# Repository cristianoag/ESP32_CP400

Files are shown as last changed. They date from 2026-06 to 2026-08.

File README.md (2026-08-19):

# The Retro Hacker Clone Series: ESP32 CP400

<p align="center">
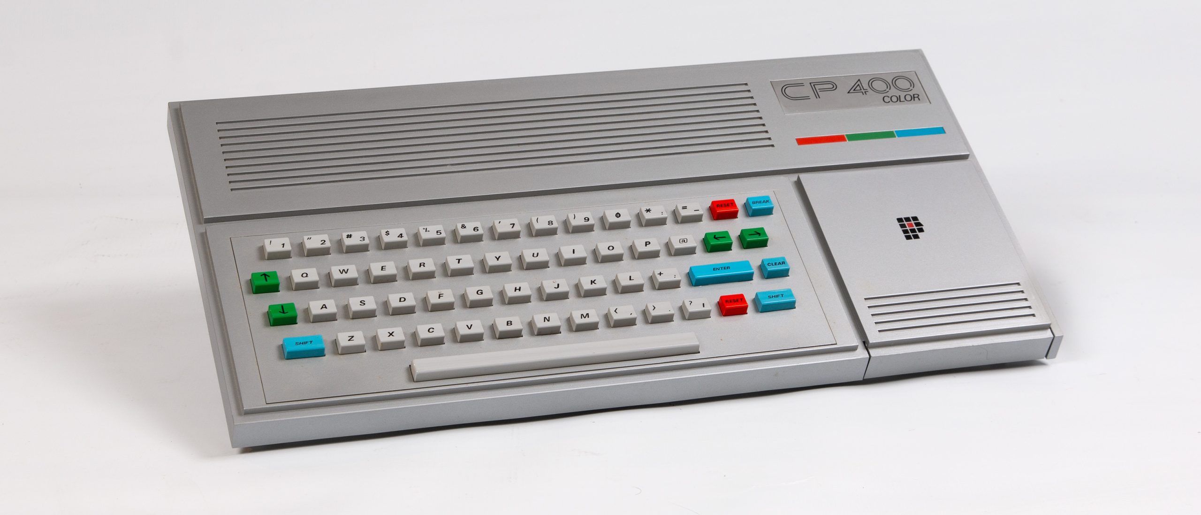
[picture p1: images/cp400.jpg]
Prologica CP 400 computer
	
</p>

An open hardware and software project to recreate the spirit of the Prologica CP 400, the Brazilian TRS-80 Color Computer 2 compatible home computer, using a modern ESP32-S3 based design.

This design is part of the Retro Hacker ESP32 Clone Series: a planned collection of ESP32-based recreations of classic Brazilian computers from the 1980s. Each machine in the series focuses on keeping the original character and software culture alive while using practical, buildable modern hardware.

The goal is not to build a museum prop. The goal is to make a usable, hackable CP400-inspired machine: real connectors, real keyboard and joystick paths, VGA output, SD-backed storage, and firmware that can run a CoCo 2 / CP400 style environment on inexpensive contemporary hardware.

## Why CP400?

The Prologica CP 400 was one of the memorable Brazilian home computers of the mid-1980s. Built during Brazil's market-reserve era, it was compatible with the Tandy/Radio Shack TRS-80 Color Computer 2, known as the CoCo 2, but arrived with its own Brazilian industrial design, PAL-M video expectations, local peripherals, translated software, and a very particular place in the local 8-bit scene.

Under the hood, the original CP400 family followed the CoCo architecture closely:

- Motorola MC6809E CPU running around 0.895 MHz
- Motorola MC6847 video display generator
- 16 KB or 64 KB RAM configurations
- Extended Color BASIC in ROM
- Cassette, cartridge, joystick, serial, video, and expansion interfaces
- Optional disk support through the CP450 floppy system

This repository explores that machine from both sides: hardware that gives the emulator a dedicated physical home, and software that recreates the CP400/CoCo experience on an ESP32-S3.

## Heritage

<p align="center">
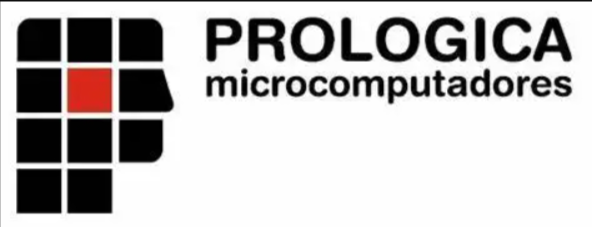
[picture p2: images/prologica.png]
Prologica logo
	
	&nbsp;&nbsp;&nbsp;&nbsp;
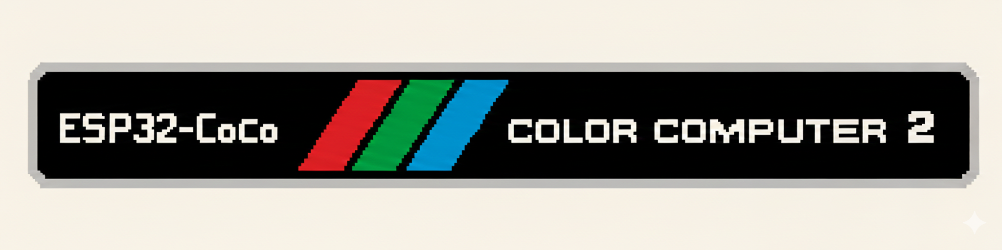
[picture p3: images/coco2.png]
TRS-80 Color Computer 2 logo
	
</p>

The ESP32 CP400 sits between two histories: Prologica's Brazilian CP400 family and the Tandy/Radio Shack CoCo 2 platform that inspired it. The project uses those references as historical anchors while building a new, independent ESP32-based recreation.

## Project Goals

- Preserve the CP400/CoCo 2 experience in a form that can be built, studied, and modified.
- Establish the CP400 entry in the broader ESP32 Clone Series for Retro Hacker.
- Use modern parts where they make sense, especially the ESP32-S3 with PSRAM.
- Provide a KiCad hardware design for a CP400-inspired board and peripheral connectors.
- Run an embedded CoCo 2 style emulator with video, USB input, SD storage, virtual disks, and joystick support.
- Keep the design approachable for retrocomputing builders, hardware hackers, and firmware tinkerers.

## Repository Layout

```text
hardware/esp32_clones/         KiCad project for the generic ESP32 clone hardware
hardware/esp32_clones/libraries Project-local KiCad symbols and footprints
software/esp32_cp400_emulator/ PlatformIO firmware for the ESP32-S3 emulator
case/                          Mechanical/case work area
```

## Hardware

The KiCad project lives in `hardware/esp32_clones` and is named `esp32_clones`.

The local KiCad libraries are organized inside:

```text
hardware/esp32_clones/libraries/symbols
hardware/esp32_clones/libraries/footprints
```

The hardware design currently includes project-local footprints and symbols for the ESP32-S3 module, USB connectors, SD card socket, switches, and other board-level parts. The intent is to give the firmware a board that feels more like a small computer than a loose dev kit on a bench.

## Firmware

The firmware lives in `software/esp32_cp400_emulator` and is built with PlatformIO using the Arduino framework for ESP32-S3.

Current software areas include:

- MC6809 emulator core integration
- CoCo 2 / CP400 video mode handling
- VGA output through the ESP32-S3 VGA library
- USB soft-host input support
- SD/MMC storage access
- Virtual floppy disk image handling
- Emulator menu and firmware updater code
- Joystick and keyboard mapping hooks

The PlatformIO environment is configured for an ESP32-S3 DevKitC-style board with 16 MB flash and 8 MB PSRAM:

```ini
[env:esp32-s3-devkitc-1-Modded]
platform = espressif32@6.11.0
board = esp32-s3-devkitc-1-n16r8
framework = arduino
```

The project intentionally pins the Espressif platform version because newer Arduino/ESP32 combinations may change includes and behavior used by the emulator.

### F12 Firmware Update Package

From `software/esp32_cp400_emulator`, generate a firmware package for the F12 update menu with:

```console
make firmware
```

The command builds the configured PlatformIO environment and creates a versioned package such as `dist/ESP32_CP400-1.11.FLH`. Copy that `.FLH` file to the root of the CP400 microSD card, then select **Firmware update** from the F12 menu.

Set the firmware version with `FW_VERSION` near the top of the Makefile, using one major digit and two minor digits. It is compiled into the F12 menu and used in the package filename. A one-off version can be built without editing the file:

```console
make firmware FW_VERSION=1.11
```

The command names can be overridden when needed, for example:

```console
make firmware PIO=platformio PYTHON=py
```

On Windows, the Makefile automatically detects PlatformIO in `%USERPROFILE%/.platformio/penv/Scripts`. Use `make help` to display the detected command.

Firmware release changes are tracked in `software/esp32_cp400_emulator/docs/log.md`.

## Status

This project is under active development. Expect the hardware, pin mapping, emulator behavior, and documentation to evolve together.

Good entry points:

- Open the KiCad project at `hardware/esp32_clones/esp32_clones.kicad_pro`.
- Open the firmware workspace at `software/esp32_cp400_emulator/esp32_cp400_emulator.code-workspace`.
- Review `software/esp32_cp400_emulator/platformio.ini` before building or uploading.

## ROMs and Original Software

Original CP400, CoCo, Extended Color BASIC, Disk BASIC, cartridge, cassette, and floppy software may still be copyrighted. This repository is for original hardware/firmware work and project files. Bring your own legally obtained ROMs and software images when needed.

## Historical Notes

The CP400 was part of a wider Brazilian TRS-Color ecosystem that included machines such as the Codimex CD-6809, LZ Color 64, Dynacom MX-1600, and Varix VC50. The CP400 became the best-known of the Brazilian CoCo-compatible machines, before the home computer market shifted heavily toward MSX and, later, IBM PC compatibles.

That makes it a particularly interesting target for a modern recreation: it sits at the meeting point of Brazilian microcomputer history, Motorola 6809 elegance, CoCo software culture, and the practical charm of 1980s home computing.

## References and Further Reading

- [Prologica CP-400](https://en.wikipedia.org/wiki/Prol%C3%B3gica_CP-400)
- [CP400](https://pt.wikipedia.org/wiki/CP400)
- [TRS-80 Color Computer](https://en.wikipedia.org/wiki/TRS-80_Color_Computer)
- [Prologica](https://pt.wikipedia.org/wiki/Prol%C3%B3gica)
- [Datassette](https://datassette.org/) for Brazilian retrocomputing manuals, magazines, books, and software preservation material

## License

See `LICENSE.txt` for the repository license. The firmware directory also includes its own `license.txt`; check both before reusing or redistributing project materials.

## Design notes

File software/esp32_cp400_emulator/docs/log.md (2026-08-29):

# Firmware Change Log

This log tracks user-visible changes to the ESP32 CP400 emulator firmware.
Versions use one major digit and two minor digits, for example 1.10 and 1.11.

## 1.13 - Unreleased

### Fixed

- Centered the 256x192 CP400 display area within the active VGA frame in every video mode. Graphics and text modes now share the same origin calculated from the selected VGA resolution instead of using separate manual offsets.

## 1.12 - 2026-08-29

### Changed

- Moved the keyboard port to the ESP32-S3 native USB-OTG host on GPIO19 and GPIO20, so ordinary full speed USB keyboards now work. The previous bit-banged stack could only talk to low speed devices, which is why most keyboards appeared dead or never lit their indicators.
- Requested the HID boot protocol from the keyboard, so keyboards that default to their own report layout still deliver the standard report the emulator expects.
- Turned the native USB serial console off, because the keyboard host and the console cannot share the one USB controller. Serial output and firmware uploads now use the UART port, which already carried the boot log.
- Kept joystick 1 and joystick 2 on the existing bit-banged stack, unchanged.

### Added

- Logged the keyboard's speed, vendor and product IDs, and the interface and endpoint in use, so an unsupported keyboard can be told apart from a power or wiring fault.
- Added `make upload` to build and upload the firmware through the PC USB port configured in `platformio.ini`.
- Added a DELETE action to eject the selected disk image from any of the four drives and persist the empty assignment.

### Fixed

- Removed UART debug writes from the 6809 timer interrupt. They caused an interrupt watchdog reset loop after the USB-OTG keyboard host moved the serial console from native USB CDC to UART0.
- Showed explicit Y/Yes and N/No choices on the firmware installation confirmation screen.
- Waited for ENTER to be released before opening the disk-drive screen, preventing the same key press from immediately opening Drive 0's file picker.

### Notes

- The keyboard connector must be rewired: D- goes to GPIO19 and D+ goes to GPIO20. These pads are tied to the USB PHY inside the chip and cannot be moved to other pins.
- Keyboards containing an internal USB hub are still not supported, because this ESP-IDF version has no hub driver.

## 1.11 - 2026-08-19

### Added

- Added a progress gauge that runs while a firmware update is validated and copied.

### Changed

- Moved the USB keyboard port to GPIO11 and GPIO12, joystick 1 to GPIO15 and GPIO16, and joystick 2 to GPIO17 and GPIO18, to simplify cable routing on the board.
- Gave every F12 screen the same layout, with the product name and screen title in the header, matching separator lines, and key hints in the footer. The disk image picker, firmware update screens, and error messages previously used their own styles.
- Renamed the "Joystick calibration" menu entry to "Joystick setup".
- Turned the joystick Serial debug output off by default.
- Listed only files with a matching extension when choosing a firmware or disk image, hiding folders such as System Volume Information that could not be opened anyway.

## 1.10 - 2026-08-18

### Added

- Added independent joystick 1 and joystick 2 control mapping from the F12 menu.
- Added guided capture for joystick neutral, up, down, left, right, button 1, and button 2 states.
- Added persistent raw HID joystick mappings to support controllers with different report layouts.
- Added a Serial joystick debug mode in the F12 menu that logs raw USB reports, decoded controls, and stored mappings at 115200 baud.
- Added a Makefile workflow that builds, packages, and verifies `.FLH` firmware updates for the F12 menu.
- Added firmware version control through the Makefile and versioned update-package filenames.

### Fixed

- Stored the PIA control registers at $FF01 and $FF03 on write, so the joystick multiplexer select bits change as the machine requests. They were never updated, which froze the multiplexer on a single channel and made every axis read return the same value.
- Restored the CP400 PIA joystick multiplexer order, which had been changed incorrectly and routed joystick 1's horizontal axis to the vertical channel while the horizontal channel read the unused second joystick.
- Centred the default joystick axis values, so a disconnected or silent joystick no longer reads as held fully left and up.
- Prevented an empty comparison mask from matching every direction at once, which cancelled horizontal and vertical movement and left the pointer centred.
- Moved joystick tracing to a dedicated task on the free core, so the video task cannot starve it and Serial output cannot disturb the bit-banged USB timing.
- Routed joystick tracing to the UART0 console used by the rest of the boot output, instead of the separate native USB serial port where it was invisible.
- Mirrored a single connected joystick's axes onto both CP400 joystick channels, so games work regardless of which joystick they read or which USB port the controller uses.
- Logged USB device enumeration with port number and vendor/product IDs, and the stored joystick mappings at boot.
- Replaced whole-report comparison with per-control bit masks so hat switches, buttons, and analog axes are matched independently.
- Excluded report bytes that change while the joystick is at rest, so counters and noisy axes no longer block button detection.
- Mapped either physical joystick button to the CP400's single fire input for that joystick.
- Added automatic detection of the standard Windows PlatformIO CLI installation.
- Corrected `.FLH` package checksums to match the F12 firmware validator.
- Fixed F12 firmware staging so stale or partial update files are replaced and verified before rebooting.

## 1.00 - 2026-08-17

### Added

- First tracked firmware release for the ESP32 CP400 emulator.
- Added CP400/CoCo 2 emulation with VGA output, USB keyboard and joystick input, SD-backed disk images, the F12 system menu, and SD-card firmware updates.

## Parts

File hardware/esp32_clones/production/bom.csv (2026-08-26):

Designator | Footprint | Quantity | Value | LCSC Part #
C1 | CP_Elec_6.3x3 | 1 | 220UF
C2 | 0805 | 1 | C
F1 | 1210 | 1 | Fuse
J1 | PS-12E05 | 1 | ~
J2 | TE_6364372-2 | 1 | Joystick 2
J3 | TE_6364372-2 | 1 | Joystick 1
J4 | TE_6364372-2 | 1 | Keyboard
J5 | Conn_uSDcard | 1 | Micro_SD_Card
J6 | BarrelJack_Horizontal | 1 | Barrel_Jack
J7 | DSUB-15-HD_Socket_Horizontal_P2.29x1.90mm_EdgePinOffset3.03mm_Housed_MountingHolesOffset4.94mm | 1 | DA15_Pins
J8 | PS-22F05 | 1 | ~
J9 | PJ-307 | 1 | AudioJack2_Ground
R1, R4, R6 | 0805 | 3 | 560R
R10 | 0805 | 1 | 1k
R2, R3, R5 | 0805 | 3 | 1.2KR
R7, R8, R9 | 0805 | 3 | 10KR
U1 | ESP32-S3-WROOM-1 | 1 | ~

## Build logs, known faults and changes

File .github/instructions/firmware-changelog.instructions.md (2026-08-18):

---
description: "Maintain the ESP32 CP400 firmware change log whenever firmware behavior, build output, configuration, or user-facing features change."
applyTo: "software/esp32_cp400_emulator/**"
---

# Firmware Change Log

For every incorporated firmware change, update `software/esp32_cp400_emulator/docs/log.md` in the same change set.

- Use the firmware version defined by `FW_VERSION` in `software/esp32_cp400_emulator/Makefile`, formatted as one major digit and two minor digits, for example `1.10`.
- Add concise, user-visible entries under `Added`, `Changed`, `Fixed`, or `Removed` as appropriate.
- Create a new version section when `FW_VERSION` changes; do not rewrite previously released sections.
- Include the release date when it is known. Use `Unreleased` when work targets a version that has not been released yet.
- Do not add entries for formatting-only edits or internal refactors with no firmware, build, configuration, or user-visible effect.

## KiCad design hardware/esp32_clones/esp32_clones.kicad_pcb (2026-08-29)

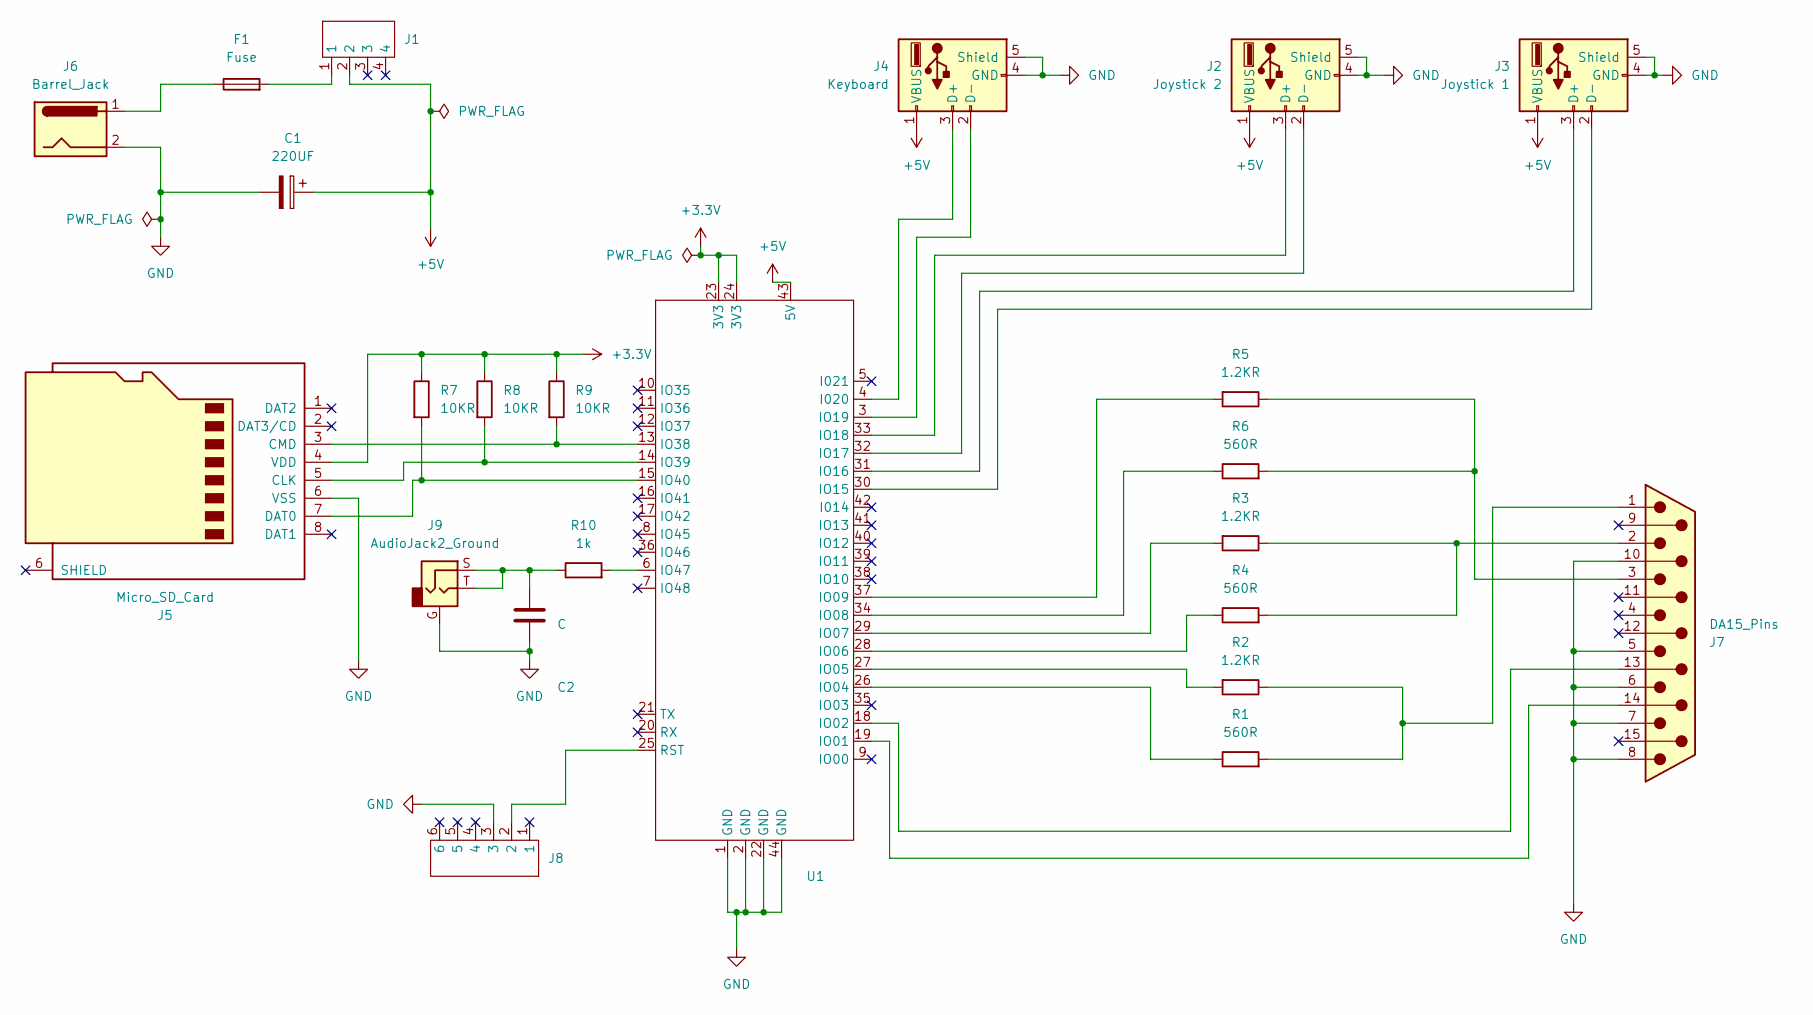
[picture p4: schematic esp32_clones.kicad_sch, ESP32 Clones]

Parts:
C1: 220UF; CP_Elec_6.3x3
C2: C; C_0805_2012Metric_Pad1.18x1.45mm_HandSolder
F1: Fuse; Fuse_1210_3225Metric
J1: PS-12E05
J2: Joystick 2; TE_6364372-2
J3: Joystick 1; TE_6364372-2
J4: Keyboard; TE_6364372-2
J5: Micro_SD_Card; Conn_uSDcard
J6: Barrel_Jack; BarrelJack_Horizontal
J7: DA15_Pins; DSUB-15-HD_Socket_Horizontal_P2.29x1.90mm_EdgePinOffset3.03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
J8: PS-22F05
J9: AudioJack2_Ground; PJ-307
R1, R4, R6: 560R; R_0805_2012Metric_Pad1.20x1.40mm_HandSolder
R2, R3, R5: 1.2KR; R_0805_2012Metric_Pad1.20x1.40mm_HandSolder
R7, R8, R9: 10KR; R_0805_2012Metric_Pad1.20x1.40mm_HandSolder
R10: 1k; R_0805_2012Metric_Pad1.20x1.40mm_HandSolder
U1: ESP32-S3-WROOM-1

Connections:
+3.3V: J5.4 (VDD), R7.1, R8.1, R9.1, U1.23 (3V3), U1.24 (3V3)
+5V: C1.1, J1.2, J2.1 (VBUS), J3.1 (VBUS), J4.1 (VBUS), U1.43 (5V)
GND: C1.2, C2.2, J2.4 (GND), J2.5 (Shield), J3.4 (GND), J3.5 (Shield), J4.4 (GND), J4.5 (Shield), J5.6 (VSS), J6.2, J7.5, J7.6, J7.7, J7.8, J7.10, J8.3, J9.G, U1.1 (GND), U1.2 (GND), U1.22 (GND), U1.44 (GND)
unnamed: C2.1, J9.S, J9.T, R10.1
unnamed: F1.1, J6.1
unnamed: F1.2, J1.1
unnamed: J2.3 (D+), U1.33 (IO18)
unnamed: J2.2 (D-), U1.32 (IO17)
unnamed: J3.3 (D+), U1.31 (IO16)
unnamed: J3.2 (D-), U1.30 (IO15)
unnamed: J4.3 (D+), U1.4 (I020)
unnamed: J4.2 (D-), U1.3 (IO19)
unnamed: J5.5 (CLK), R8.2, U1.14 (IO39)
unnamed: J5.3 (CMD), R9.2, U1.13 (IO38)
unnamed: J5.7 (DAT0), R7.2, U1.15 (IO40)
unnamed: J7.13, U1.18 (IO02)
unnamed: J7.14, U1.19 (IO01)
unnamed: J7.1, R1.2, R2.1
unnamed: J7.2, R3.1, R4.2
unnamed: J7.3, R5.1, R6.2
unnamed: R1.1, U1.26 (IO04)
unnamed: R2.2, U1.27 (IO05)
unnamed: R4.1, U1.28 (IO06)
unnamed: R3.2, U1.29 (IO07)
unnamed: R6.1, U1.34 (IO08)
unnamed: R5.2, U1.37 (IO09)
unnamed: R10.2, U1.6 (IO47)
unnamed: J8.2, U1.25 (RST)

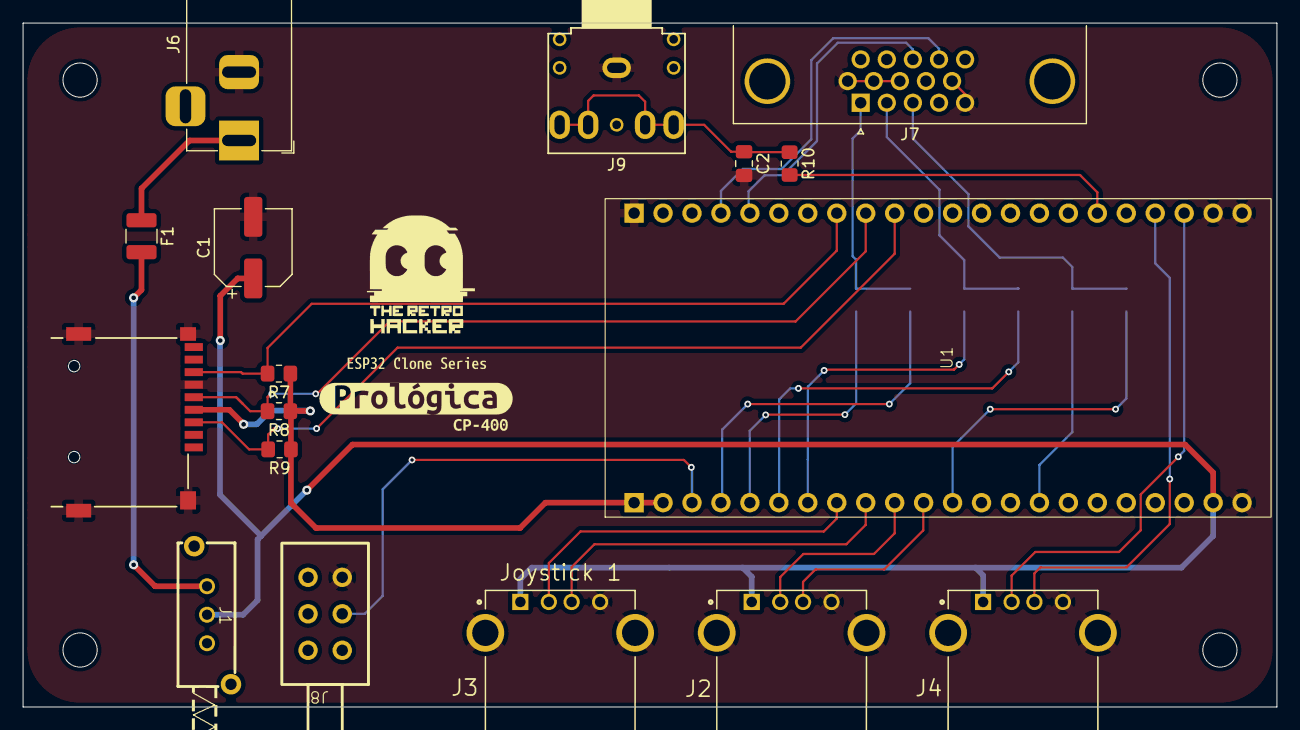
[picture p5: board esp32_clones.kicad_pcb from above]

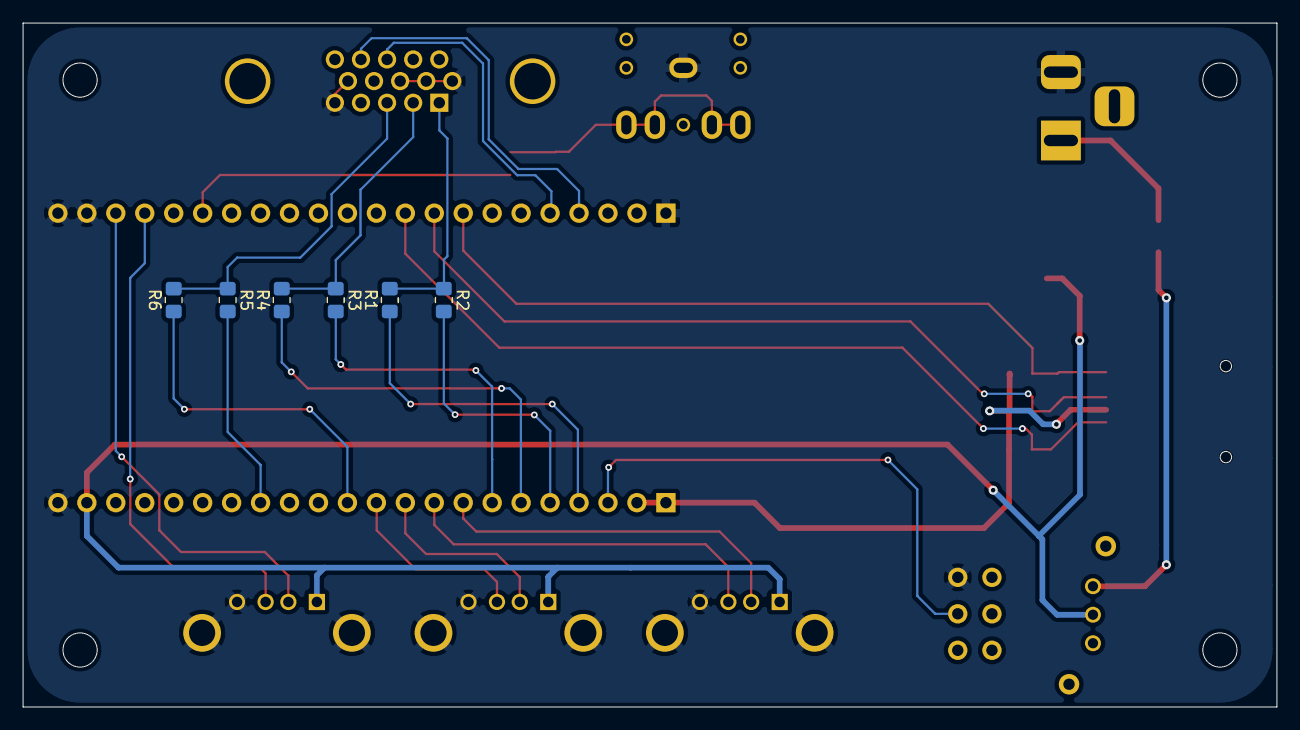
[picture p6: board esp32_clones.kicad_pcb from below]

Board: 2 copper layers, 110.0 x 60.0 mm, 26 parts (6 on the bottom side), 28 nets.

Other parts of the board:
kibuzzard-6A32A22E: G***; kibuzzard-6A32A22E
kibuzzard-6A32A25A: G***; kibuzzard-6A32A25A
kibuzzard-6A32A222: G***; kibuzzard-6A32A222

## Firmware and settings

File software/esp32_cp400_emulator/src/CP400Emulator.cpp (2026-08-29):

/******************************************************************************
 * Project      : esp32_cp400_emulator
 * File         : CP400Emulator.cpp
 * Last Updated : 2026-08-17
 *
 * Description  : CP400 emulator main code (CPU core, video, disk, peripherals)
 *
 * Original work copyright (c) 2026 Cedric Beaudoin
 * CP400 code and modifications copyright (c) 2026 The Retro Hacker
 *
 * Permission is granted for personal, non-commercial use only.
 * Commercial use, distribution, sublicensing, or modification
 * for commercial purposes is strictly prohibited without
 * prior written permission from the author.
 * Please, keep this in the source code.
 * All rights reserved.
 ******************************************************************************/




#include <Arduino.h>
#include "mc6809.hpp"
#include "esp_timer.h"
#include "esp_system.h"

#include "CP400Emulator.h"

#include "ESP32S3vga.h"
#include <GfxWrapper.h>
#include <Fonts/FreeMonoBoldOblique24pt7b.h>
#include <Fonts/FreeSerif24pt7b.h>
#include <Fonts/FreeMono9pt7b.h>



//----------------------------USB STACK-------------------------------------

#include <ESP32-USB-Soft-Host.h>
#include "CP400Input.h"
#include "CP400UsbKeyboard.h"
#define KEY_SHIFT_LEFT




USB_DEVICES_CTRL USB_DEV_CONTROL;



  //Each pin pair is one USB connector: P1 joystick 1, P2 joystick 2.
  //The keyboard no longer uses the soft host. It runs on the USB-OTG controller
  //through GPIO19 and GPIO20 so full speed keyboards enumerate, which the
  //bit-banged stack could never do. See CP400UsbKeyboard.cpp.
  #define DP_P0  -1
  #define DM_P0  -1
  #define DP_P1  16
  #define DM_P1  15
  #define DP_P2  18
  #define DM_P2  17
  #define DP_P3  -1
  #define DM_P3  -1

extern USB_DEVICES_CTRL USB_DEV_CONTROL;

extern void Setup_USB(void);





//-----------------------------------------------------------



#define LED_PORT_ANODE 45
#define LED_PORT_CATHODE 46

#define LED_PORT_CATHODE_HI() GPIO.out1_w1ts.val = (1 << (LED_PORT_CATHODE - 32));  // Set HIGH
#define LED_PORT_CATHODE_LOW() GPIO.out1_w1tc.val = (1 << (LED_PORT_CATHODE - 32));  // Set LOW

#define LED_PORT_ANODE_HI() GPIO.out1_w1ts.val = (1 << (LED_PORT_ANODE - 32));  // Set HIGH
#define LED_PORT_ANODE_LOW()  GPIO.out1_w1tc.val = (1 << (LED_PORT_ANODE - 32));  // Set LOW

void inline DISKETTE_LED_ON(void)
{
  LED_PORT_CATHODE_HI();
  LED_PORT_ANODE_LOW();
}
void inline DISKETTE_LED_OFF(void)
{
  LED_PORT_CATHODE_LOW();
  LED_PORT_ANODE_HI();
}
void inline DISKETTE_LED_FLOAT(void)
{
  LED_PORT_CATHODE_LOW();
  LED_PORT_ANODE_LOW();
}




uint8_t uint8_t_VarGlobal;
uint8_t DEBUGloop1, DEBUGloop2;
void Debug1Toggle(void)
{
  if ((DEBUGloop1 & 0b00000001) == 0)
  {
    GPIO.out_w1ts = (1 << DEBUG1);
  }
  else
  {
    GPIO.out_w1tc = (1 << DEBUG1);
  }
  DEBUGloop1++;
}
void Debug2Toggle(void)
{
  if ((DEBUGloop2 & 0b00000001) == 0)
  {
    GPIO.out_w1ts = (1 << DEBUG2);
  }
  else
  {
    GPIO.out_w1tc = (1 << DEBUG2);
  }
  DEBUGloop2++;
}

void Debug2Hi(void)
{
    GPIO.out_w1ts = (1 << DEBUG2);
}

void Debug2Low(void)
{
    GPIO.out_w1tc = (1 << DEBUG2);
}



uint8_t ResetVectors[16] = {0xA6, 0x81, 0x01, 0x00, 0x01, 0x03, 0x01, 0x0F,
	0x01, 0x0C, 0x01, 0x06, 0x01, 0x09, 0xA0, 0x27};




bool CPU_in_WAIT_STATE = false;



File file;
bool SD_Card_Mounted = false;


#ifndef ISR_CORE
char text_buffer[150];
#endif



uint8_t *MENU_Backup = (uint8_t *)heap_caps_malloc(640*250, MALLOC_CAP_SPIRAM);
uint8_t *MENU_BackupPage2 = (uint8_t *)heap_caps_malloc(640*250, MALLOC_CAP_SPIRAM);
#define DISK_SIZE 161280

uint8_t *RAM_Disk0 = (uint8_t *)heap_caps_malloc(161280, MALLOC_CAP_SPIRAM);
uint8_t *RAM_Disk1 = (uint8_t *)heap_caps_malloc(161280, MALLOC_CAP_SPIRAM);
uint8_t *RAM_Disk2 = (uint8_t *)heap_caps_malloc(161280, MALLOC_CAP_SPIRAM);
uint8_t *RAM_Disk3 = (uint8_t *)heap_caps_malloc(161280, MALLOC_CAP_SPIRAM);
#ifdef PSRAM_EMU
uint8_t *rom = (uint8_t *)heap_caps_malloc(32769, MALLOC_CAP_SPIRAM);
uint8_t *memory = (uint8_t *)heap_caps_malloc(65536, MALLOC_CAP_SPIRAM);
#else
uint8_t rom[32769];
uint8_t memory[65536];
#endif



SpecialFunctionStruct sf;

struct DiskAccessStruct
{
  uint8_t TrackPos;
  uint8_t DriveSelected;
  uint8_t MotorOnOff;
  uint8_t SectorPos;
  uint8_t DRIVE_COMMAND;
  uint8_t DataRegisterValue;
  uint32_t DSK_FILE_DataPTR;
  bool IsinReadProcess;
  bool IsInWriteProcess;
  bool NMI_Int_Started;
  uint8_t NMI_Delay;    //To Allow the CP400 to read the last byte from the FD502 before the NMI.
  uint16_t RW_Process_ByteRemainingCounter;
};

DiskAccessStruct DiskAccess;


DriveStruct Disk_Drive;
DiskRomSelection selectedDiskRom = DiskRomSelection::CP400;



  class cpu_t : public mc6809 
{
  public:
      uint8_t read8(uint16_t address) const 
      {
        uint8_t t_data;
        ManagePeripherals_Read(address);
      if (!sf.CP400_32K_UPPER_ENABLED)
      {
        if ((address > 0x7fff))
        {

          return rom[address - ROM_OFFSET];
        }
        else
        {
          return memory[address];
        }

      }
      else
      {
        if ((address > 0xdfff))
        {
          
          return rom[address - ROM_OFFSET];
        }
        else
        {
          return memory[address];
        }
      }

        return 0;
      }

      

      void write8(uint16_t address, uint8_t value) const 
      {
          ManagePeripherals_Write(address , value);


        if (!sf.CP400_32K_UPPER_ENABLED)
        {
          if (address >0x7fff)
          {
              
              //rom[address - 0x8000] = value;
          
          } 
          else
          {
              memory[address] = value;
          }
        }
        else
        {
              memory[address] = value;
        }



          
        }


};



bool ReadCP400DiskImage(const char* filename, uint8_t DriveNumber)
{
    if (!SD_Card_Mounted)
    {
      return false;
    }
    
    
    size_t bytesRead;
    File f = SD_MMC.open(filename, FILE_READ);
    if(!f)
    {
#ifdef DEBUG_PRINT    
        Serial.print("Failed to open file: ");
        Serial.println(filename);
#endif
        return false;
    }

    
    switch (DriveNumber)
    {
    case 0:
      bytesRead = f.read(RAM_Disk0, DISK_SIZE);
    break;
    case 1:
      bytesRead = f.read(RAM_Disk1, DISK_SIZE);
    break;
    case 2:
      bytesRead = f.read(RAM_Disk2, DISK_SIZE);
    break;
    case 3:
      bytesRead = f.read(RAM_Disk3, DISK_SIZE);
    break;
    
    default:
      break;
    }
    
    

#ifdef DEBUG_PRINT    
    Serial.print("Read ");
    Serial.print(bytesRead);
    Serial.print(" bytes into RAM_Disk ");
    Serial.println(DriveNumber);
#endif
    f.close();
    

    return true;
}

bool SaveConfigToSD(void) 
{
    if (!SD_Card_Mounted)
    {
      return false;
    }

    if (SD_MMC.exists("/config.ccc") && !SD_MMC.remove("/config.ccc"))
    {
      Serial.println("Failed to replace /config.ccc");
      return false;
    }

    File f = SD_MMC.open("/config.ccc", FILE_WRITE);
    if (!f) {
        Serial.println("Failed to open /config.ccc for writing");
        return false;
    }

    for (int i = 0; i < 4; i++) 
    {
        size_t written = f.write(Disk_Drive.Name_Disk[i], 256);
        if (written != 256) 
        {
            Serial.printf("Write failed for disk %d\n", i);
            f.close();
            return false;
        }
    }

    const uint8_t diskRomValue = static_cast<uint8_t>(selectedDiskRom);
    if (f.write(&diskRomValue, sizeof(diskRomValue)) != sizeof(diskRomValue))
    {
        Serial.println("Failed to save Disk ROM selection");
        f.close();
        return false;
    }

    const uint8_t calibrationHeader[] = {'J', 'C', 'A', 'L', 4};
    if (f.write(calibrationHeader, sizeof(calibrationHeader)) != sizeof(calibrationHeader) ||
      f.write(reinterpret_cast<const uint8_t*>(USB_DEV_CONTROL.JOYSTICK_CALIBRATION),
          sizeof(USB_DEV_CONTROL.JOYSTICK_CALIBRATION)) != sizeof(USB_DEV_CONTROL.JOYSTICK_CALIBRATION))
    {
      Serial.println("Failed to save joystick calibration");
      f.close();
      return false;
    }

    f.close();
    Serial.println("Configuration saved to SD");
    return true;
}

bool LoadConfigFromSD(void)
{
  memset(USB_DEV_CONTROL.JOYSTICK_CALIBRATION, 0,
       sizeof(USB_DEV_CONTROL.JOYSTICK_CALIBRATION));

    if (!SD_Card_Mounted)
    {
      return false;
    }

    File f = SD_MMC.open("/config.ccc", FILE_READ);
    if (!f) 
    {
        Serial.println("Failed to open /config.ccc for reading");
        return false;
    }

    for (int i = 0; i < 4; i++) 
    {
        size_t readBytes = f.read(Disk_Drive.Name_Disk[i], 256);
        if (readBytes != 256) 
        {
            Serial.printf("Read failed for disk %d\n", i);
            f.close();
            return false;
        }
    }

    uint8_t diskRomValue = static_cast<uint8_t>(DiskRomSelection::CP400);
    const size_t selectionBytes = f.read(&diskRomValue, sizeof(diskRomValue));
    if (selectionBytes == 0)
    {
        Serial.println("Legacy configuration found; using CP400 Disk ROM");
        selectedDiskRom = DiskRomSelection::CP400;
    }
    else if (diskRomValue <= static_cast<uint8_t>(DiskRomSelection::CoCo2))
    {
        selectedDiskRom = static_cast<DiskRomSelection>(diskRomValue);
    }
    else
    {
        Serial.println("Invalid Disk ROM selection; using CP400 Disk ROM");
        selectedDiskRom = DiskRomSelection::CP400;
    }

    uint8_t calibrationHeader[5];
    JoystickCalibration calibration[2];
    if (f.read(calibrationHeader, sizeof(calibrationHeader)) == sizeof(calibrationHeader) &&
      memcmp(calibrationHeader, "JCAL\x04", sizeof(calibrationHeader)) == 0 &&
      f.read(reinterpret_cast<uint8_t*>(calibration), sizeof(calibration)) == sizeof(calibration))
    {
      for (uint8_t joystick = 0; joystick < 2; joystick++)
      {
        if (calibration[joystick].valid && calibration[joystick].reportLength > 0 &&
            calibration[joystick].reportLength <= JOYSTICK_REPORT_SIZE)
        {
          USB_DEV_CONTROL.JOYSTICK_CALIBRATION[joystick] = calibration[joystick];
        }
      }
    }

    f.close();
    Serial.println("Configuration loaded from SD");
    return true;
}

bool EjectCP400Disk(uint8_t DriveNumber)
{
  if (DriveNumber >= 4)
  {
    return false;
  }

  uint8_t previousName[sizeof(Disk_Drive.Name_Disk[DriveNumber])];
  memcpy(previousName, Disk_Drive.Name_Disk[DriveNumber], sizeof(previousName));
  memset(Disk_Drive.Name_Disk[DriveNumber], 0, sizeof(Disk_Drive.Name_Disk[DriveNumber]));

  if (!SaveConfigToSD())
  {
    memcpy(Disk_Drive.Name_Disk[DriveNumber], previousName, sizeof(previousName));
    return false;
  }

  uint8_t *diskMemory = nullptr;
  switch (DriveNumber)
  {
  case 0:
    diskMemory = RAM_Disk0;
    break;
  case 1:
    diskMemory = RAM_Disk1;
    break;
  case 2:
    diskMemory = RAM_Disk2;
    break;
  case 3:
    diskMemory = RAM_Disk3;
    break;
  }

  if (diskMemory != nullptr)
  {
    memset(diskMemory, 0xFF, DISK_SIZE);
  }

  if (DiskAccess.DriveSelected == DriveNumber)
  {
    DiskAccess.IsinReadProcess = false;
    DiskAccess.IsInWriteProcess = false;
    DiskAccess.RW_Process_ByteRemainingCounter = 0;
    sf.PHYSICAL_Drive_Must_Be_Saved = false;
  }

  return true;
}


bool WriteCP400DiskImage(const char* filename, uint8_t DriveNumber)
{
  //return true;
  if (!SD_Card_Mounted)
  {
    return false;
  }

  size_t bytesWritten = 0;
    
    
    File f = SD_MMC.open(filename, FILE_WRITE);
    if(!f)
    {
#ifdef DEBUG_PRINT    
      Serial.print("Failed to open file for writing: ");
      Serial.println(filename);
#endif
      return false;
    }

    switch(DriveNumber)
    {
        case 0:
            bytesWritten = f.write(RAM_Disk0, DISK_SIZE);
        break;

        case 1:
            bytesWritten = f.write(RAM_Disk1, DISK_SIZE);
        break;

        case 2:
            bytesWritten = f.write(RAM_Disk2, DISK_SIZE);
        break;

        case 3:
        bytesWritten = f.write(RAM_Disk3, DISK_SIZE);
        break;

        default:
#ifdef DEBUG_PRINT    
        Serial.println("Invalid DriveNumber");
#endif
        f.close();
        return false;
    }

    f.flush();     // force physical write
    f.close();

#ifdef DEBUG_PRINT    
    Serial.print("Written ");
    Serial.print(bytesWritten);
    Serial.print(" bytes from RAM_Disk ");
    Serial.println(DriveNumber);
#endif
    return (bytesWritten == DISK_SIZE);
}




cpu_t cpu;

void DoCPU(void)
{
  //Debug1Toggle();
  
  if (CPU_in_WAIT_STATE)
  {
    if (sf.CPU_HALTED_BY_EMULATOR) //If Emulator is in Menus, 
    {
      return;
    }
    
    if (gpio_get_level(VSYNC_PORT) != 0)  //Manage CWAI instruction
    {
      return;
    }
    else
    {
      CPU_in_WAIT_STATE = false;
    }
  }
  //Debug1Toggle();
  
  cpu.execute();
  cpu.execute();
  if (sf.CPU_Speed == CPU_FAST)
  {
    cpu.execute();
    cpu.execute();
  }

  return;
}

void CopyDiskToRamDisk(void)
{
  if (!SD_Card_Mounted)
  {
    return;
  }

  ReadCP400DiskImage((const char*)Disk_Drive.Name_Disk[0], 0);
  ReadCP400DiskImage((const char*)Disk_Drive.Name_Disk[1], 1);
  ReadCP400DiskImage((const char*)Disk_Drive.Name_Disk[2], 2);
  ReadCP400DiskImage((const char*)Disk_Drive.Name_Disk[3], 3);
  
}



  const PinConfig pins(-1,-1,-1,5,4,  -1,-1,-1,-1,7,6,  -1,-1,-1,9,8,  2,1);
//                             B B X       G  G  X         R  R
    //6 bit mode for Coco 3    0 1 X       0  1  X         0  1

VGA* vga;
GfxWrapper<VGA> *gfx;


Mode mode0 = Mode::MODE_320x240x60;
Mode mode1 = Mode::MODE_320x240x60_4_3;
Mode mode2 = Mode::MODE_640x240x60;
Mode mode3 = Mode::MODE_640x240x60_4_3;

constexpr uint16_t VIDEO_ACTIVE_WIDTH = 256;
constexpr uint16_t VIDEO_ACTIVE_HEIGHT = 192;
uint16_t VideoViewportX = (mode1.hRes - VIDEO_ACTIVE_WIDTH) / 2;
uint16_t VideoViewportY = (mode1.vRes - VIDEO_ACTIVE_HEIGHT) / 2;

#define VIDEO_GRAPHICS_X_OFFSET VideoViewportX
#define VIDEO_Y_OFFSET VideoViewportY

void SetVideoViewport(const Mode &mode)
{
  sf.VideoEmulatorXpixels = mode.hRes;
  VideoViewportX = mode.hRes > VIDEO_ACTIVE_WIDTH
                     ? (mode.hRes - VIDEO_ACTIVE_WIDTH) / 2
                     : 0;
  VideoViewportY = mode.vRes > VIDEO_ACTIVE_HEIGHT
                     ? (mode.vRes - VIDEO_ACTIVE_HEIGHT) / 2
                     : 0;
}



uint8_t SCAN_Keyboard_Matrix[8][7];


uint8_t ReadCP400Buttons(void)
{
  uint8_t val1, val2;
  val1 = USB_DEV_CONTROL.JOY1_BUTT1 & USB_DEV_CONTROL.JOY1_BUTT2;
  val2 = (USB_DEV_CONTROL.JOY2_BUTT1 & USB_DEV_CONTROL.JOY2_BUTT2) << 1;

  return val1 | val2;
  
}

void InitSD_Card1(void)
{
  SD_MMC.setPins(SD_MMC_CLK, SD_MMC_CMD, SD_MMC_D0);
  if (!SD_MMC.begin("/sdcard", true, false, SDMMC_FREQ_DEFAULT, 5)) 
  {
    Serial.println("Card Mount Failed");
    return;
  }

 file = SD_MMC.open("/GAMES01.DSK", FILE_READ);
  if (!file)
  {
    Serial.println("Failed to open /GAMES01.DSK");
    return;
  }
  else
  {
    Serial.println("File Correct");
  }
  while(1)
  {

  }
}
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
void loop()
{
  //Nothig to do here, all the work is in ISR and RTOS
}


#define CP400_GRAPH_MODE_32X16_8X12 0b0 //Text 32x16
#define CP400_GRAPH_MODE_256X192X2 0b11110110  //PMODE 4
#define CP400_GRAPH_MODE_128X192X4 0b11100110  //PMODE 3  OK


#define CP400_GRAPH_MODE_128X192X2 0b11010101  //PMODE 2
#define CP400_GRAPH_MODE_128X96X4 0b11000100  //PMODE 1
#define CP400_GRAPH_MODE_128X96X4_1 0b11110100  //PMODE 1 Other mode??


#define CP400_GRAPH_MODE_128X96X2 0b10110011  //PMODE 0


//---------Other modes in assembly language only, not officialy supported in Basic CP400
#define CP400_GRAPH_MODE_128X64X4 0b10100010  //
#define CP400_GRAPH_MODE_128X64X2 0b10010001  //

#define CP400_GRAPH_MODE_64X64X4 0b10000001  //


#ifdef DEBUG_ALL
#define WAIT_VSYNCH_LOW()  while(gpio_get_level(VSYNC_PORT) != 0) {DEBUG1_SET;}DEBUG1_CLR
#else
#define WAIT_VSYNCH_LOW()  while(gpio_get_level(VSYNC_PORT) != 0) {}
#endif
void IRAM_ATTR VideoCore(void *pvParameters) 
{
  uint8_t ModeValue;
  while (true) 
  {
    //vTaskDelay(1);
    if (sf.DIRECT_Key_Code == MENU_F12) //Emulator menu entrance
    {
      
      CPU_in_WAIT_STATE = true;
      sf.CPU_HALTED_BY_EMULATOR = true;
      vTaskDelay(1);

      EMULATOR_Menu();
      CPU_in_WAIT_STATE = false;
      sf.CPU_HALTED_BY_EMULATOR = false;
      vTaskDelay(200);
    }
    



    ModeValue = sf.CP400GraphicMode & 0b11110111;    //Remove the Color bit
    
    switch (ModeValue)
    {
    
      case CP400_GRAPH_MODE_32X16_8X12:
        RenderCP400GraphMode_32X16_8X12();
      break;

      case CP400_GRAPH_MODE_256X192X2:
        if (sf.Artefact)
        {
          RenderCP400GraphMode_256X192X2_Artefact();
        }
        else
        {
          RenderCP400GraphMode_256X192X2();
        }
      break;

      case CP400_GRAPH_MODE_128X192X4:
        RenderCP400GraphMode_128X192X4();
      break;

      case CP400_GRAPH_MODE_128X192X2:
        RenderCP400GraphMode_128X192X2();
      break;

      case CP400_GRAPH_MODE_128X96X4:
      case CP400_GRAPH_MODE_128X96X4_1:
      RenderCP400GraphMode_128X96X4();
      break;

      case CP400_GRAPH_MODE_128X96X2:
        RenderCP400GraphMode_128X96X2();
      break;

      case CP400_GRAPH_MODE_128X64X4:
        RenderCP400GraphMode_128X64X4();
      break;

      case CP400_GRAPH_MODE_128X64X2:
        RenderCP400GraphMode_128X64X2();
    break;

    case CP400_GRAPH_MODE_64X64X4:
      RenderCP400GraphMode_64X64X4();
break;

      
      
      default:
      break;
    }

    
    
    /*
    while (!sf.V_Synch) //While no interrupt
    {
      //vTaskDelay(1);
      NOP();
    }*/


    WAIT_VSYNCH_LOW();
    Field_Synch_Interrupt_Flag();
  
    vga->show();
    
    if (sf.PHYSICAL_Drive_Must_Be_Saved)
    {
      DISKETTE_LED_ON();
      WriteCP400DiskImage((const char*)Disk_Drive.Name_Disk[DiskAccess.DriveSelected],DiskAccess.DriveSelected);
      DISKETTE_LED_OFF();
      sf.PHYSICAL_Drive_Must_Be_Saved = false;
    }

    FillKeyboardMatrix();
  }
}


void RenderCP400GraphMode_64X64X4(void)
{


  if (sf.CP400VideoGenMODE != CP400_GRAPH_MODE_64X64X4)
  {
    vga->clear(0b11111111);
    vga->show();
    vga->clear(0b11111111);
    vga->show();

    sf.CP400VideoGenMODE = CP400_GRAPH_MODE_64X64X4;
  }




  
  uint32_t MemLoop = sf.CP400VideoPageOffset_Registers * CP400_GRAPH_OFFSET_LEN;
  uint16_t Xloop, Yloop, Yloop1;
  uint8_t Dot1bit[8];
  uint8_t Color[4];
  
  if ((sf.CP400GraphicMode & 0b00001000) == 0)
  {
    Color[0] = RGB332ToVGAPacked(0b00011100);  //Green
    Color[1] = RGB332ToVGAPacked(0b11111100);  //Yellow
    Color[2] = RGB332ToVGAPacked(0b00000011);  //Blue
    Color[3] = RGB332ToVGAPacked(0b11100000);  //Red
  }
  else
  {
    Color[0] = RGB332ToVGAPacked(0xff); //blanc
    Color[1] = RGB332ToVGAPacked(0b01011011);  //Turquoise
    Color[2] = RGB332ToVGAPacked(0b11100011);  //lilas
    Color[3] = RGB332ToVGAPacked(0b11101000);  //orange(buff)
  }  

  for (Yloop = VIDEO_Y_OFFSET; Yloop < VIDEO_Y_OFFSET + VIDEO_ACTIVE_HEIGHT; Yloop+=3)
  {
        for (Xloop = VIDEO_GRAPHICS_X_OFFSET; Xloop < VIDEO_GRAPHICS_X_OFFSET + 256; Xloop+=16)
    {

      Dot1bit[3] = (memory[MemLoop] >> 6) & 0b11;  // Bits 6-7
      Dot1bit[2] = (memory[MemLoop] >> 4) & 0b11;  // Bits 4-5
      Dot1bit[1] = (memory[MemLoop] >> 2) & 0b11;  // Bits 2-3
      Dot1bit[0] = (memory[MemLoop++] >> 0) & 0b11;  // Bits 0-1

      //Line one
      vga->dot(Xloop,Yloop, Color[Dot1bit[3]]);
      vga->dot(Xloop+1,Yloop, Color[Dot1bit[3]]);
      vga->dot(Xloop+2,Yloop, Color[Dot1bit[3]]);
      vga->dot(Xloop+3,Yloop, Color[Dot1bit[3]]);

      vga->dot(Xloop+4,Yloop, Color[Dot1bit[2]]);
      vga->dot(Xloop+5,Yloop, Color[Dot1bit[2]]);
      vga->dot(Xloop+6,Yloop, Color[Dot1bit[2]]);
      vga->dot(Xloop+7,Yloop, Color[Dot1bit[2]]);

      vga->dot(Xloop+8,Yloop, Color[Dot1bit[1]]);
      vga->dot(Xloop+9,Yloop, Color[Dot1bit[1]]);
      vga->dot(Xloop+10,Yloop, Color[Dot1bit[1]]);
      vga->dot(Xloop+11,Yloop, Color[Dot1bit[1]]);

      vga->dot(Xloop+12,Yloop, Color[Dot1bit[0]]);
      vga->dot(Xloop+13,Yloop, Color[Dot1bit[0]]);
      vga->dot(Xloop+14,Yloop, Color[Dot1bit[0]]);
      vga->dot(Xloop+15,Yloop, Color[Dot1bit[0]]);

      Yloop1 = Yloop+1;
      //Line 2

      vga->dot(Xloop,Yloop1, Color[Dot1bit[3]]);
      vga->dot(Xloop+1,Yloop1, Color[Dot1bit[3]]);
      vga->dot(Xloop+2,Yloop1, Color[Dot1bit[3]]);
      vga->dot(Xloop+3,Yloop1, Color[Dot1bit[3]]);

      vga->dot(Xloop+4,Yloop1, Color[Dot1bit[2]]);
      vga->dot(Xloop+5,Yloop1, Color[Dot1bit[2]]);
      vga->dot(Xloop+6,Yloop1, Color[Dot1bit[2]]);
      vga->dot(Xloop+7,Yloop1, Color[Dot1bit[2]]);

      vga->dot(Xloop+8,Yloop1, Color[Dot1bit[1]]);
      vga->dot(Xloop+9,Yloop1, Color[Dot1bit[1]]);
      vga->dot(Xloop+10,Yloop1, Color[Dot1bit[1]]);
      vga->dot(Xloop+11,Yloop1, Color[Dot1bit[1]]);

      vga->dot(Xloop+12,Yloop1, Color[Dot1bit[0]]);
      vga->dot(Xloop+13,Yloop1, Color[Dot1bit[0]]);
      vga->dot(Xloop+14,Yloop1, Color[Dot1bit[0]]);
      vga->dot(Xloop+15,Yloop1, Color[Dot1bit[0]]);
      //Line 3
      Yloop1++;

      vga->dot(Xloop,Yloop1, Color[Dot1bit[3]]);
      vga->dot(Xloop+1,Yloop1, Color[Dot1bit[3]]);
      vga->dot(Xloop+2,Yloop1, Color[Dot1bit[3]]);
      vga->dot(Xloop+3,Yloop1, Color[Dot1bit[3]]);

      vga->dot(Xloop+4,Yloop1, Color[Dot1bit[2]]);
      vga->dot(Xloop+5,Yloop1, Color[Dot1bit[2]]);
      vga->dot(Xloop+6,Yloop1, Color[Dot1bit[2]]);
      vga->dot(Xloop+7,Yloop1, Color[Dot1bit[2]]);

      vga->dot(Xloop+8,Yloop1, Color[Dot1bit[1]]);
      vga->dot(Xloop+9,Yloop1, Color[Dot1bit[1]]);
      vga->dot(Xloop+10,Yloop1, Color[Dot1bit[1]]);
      vga->dot(Xloop+11,Yloop1, Color[Dot1bit[1]]);

      vga->dot(Xloop+12,Yloop1, Color[Dot1bit[0]]);
      vga->dot(Xloop+13,Yloop1, Color[Dot1bit[0]]);
      vga->dot(Xloop+14,Yloop1, Color[Dot1bit[0]]);
      vga->dot(Xloop+15,Yloop1, Color[Dot1bit[0]]);

      
    }
  }

}
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

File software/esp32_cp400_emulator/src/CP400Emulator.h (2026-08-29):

/******************************************************************************
 * Project      : esp32_cp400_emulator
 * File         : CP400Emulator.h
 * Last Updated : 2026-08-17
 *
 * Description  : Core CP400 emulator definitions, structures and declarations
 *
 * Original work copyright (c) 2026 Cedric Beaudoin
 * CP400 code and modifications copyright (c) 2026 The Retro Hacker
 *
 * Permission is granted for personal, non-commercial use only.
 * Commercial use, distribution, sublicensing, or modification
 * for commercial purposes is strictly prohibited without
 * prior written permission from the author.
 * Please, keep this in the source code.
 * All rights reserved.
 ******************************************************************************/


#ifndef CP400_EMULATOR_H
#define CP400_EMULATOR_H


#include "driver/adc.h"
#include "esp_adc_cal.h"
#include "SD_MMC.h"
#include "CP400Menu.h"
#include "CP400Roms.h"
#include <EEPROM.h>
//----------------------
#define VSYNC_PORT GPIO_NUM_1
#define HSYNC_PORT GPIO_NUM_2




#define PSRAM_EMU
//#define DEBUG_ALL
//#define DEBUG_PRINT
//#define PRINT_DEBUG

//------------
#ifdef PRINT_DEBUG
#define debug Serial.print
#define debugln Serial.println
#define debugf Serial.printf
#else
#define debug //
#define debugln //
#define debugf //
#endif


#define DEBUG1_SET GPIO.out_w1ts = (1 << DEBUG1)
#define DEBUG1_CLR GPIO.out_w1tc = (1 << DEBUG1)


#define MACRO_DO_CASSETTE_BIT_OUTPUT \
if ((value & 0b00000010) == 0) \
{ \
    GPIO.out_w1tc = (1 << BOARD_CASSETTE_OUT);  /* Output 0 */ \
} \
else \
{ \
    GPIO.out_w1ts = (1 << BOARD_CASSETTE_OUT);  /* Output 1 */ \
}


struct SpecialFunctionStruct
{
  uint8_t DIRECT_Key_Code;
  bool CPU_HALTED_BY_EMULATOR; //CPU Halted because the Emulator is in menus.
  bool PHYSICAL_Drive_Must_Be_Saved; //To Save VIrtual Disk to Physical SD Card.
  bool nmi_pin; //Mapped to CPU pîn NMI
  bool firq_pin; //Mapped to CPU pîn FIRQ
  bool irq_pin; //Mapped to CPU pîn IRQ
  bool V_Synch;
  bool V_Synch_Int_Enabled;
  uint16_t ROM_Offset; //Rom address offset wuen executing from ROM address.
  bool AnyKeypress;   //Global VAR for any keypress check;
  bool CP400Mode;   //True at boot
  bool CP400VideoMode;
  bool CPU_Speed;
  uint8_t CP400VideoGenMODE;
  uint8_t CP400GraphicMode;
  bool CP400_32K_UPPER_ENABLED;
  uint8_t CP400ColorMode;
  uint8_t CP400VideoPageOffset_Registers;   //7 bits data of SET/CLR only offset register to do mult to final usable offset of CP400VideoPageOffset
  uint16_t VideoEmulatorXpixels;   //define the number of X pixel to center the Emulation screen.
  bool is_JOY1_B1_WasPressed;
  bool is_JOY1_B2_WasPressed;
  bool is_JOY2_B1_WasPressed;
  bool is_JOY2_B2_WasPressed;
  bool is_LastKeyboardScanned;
  bool Artefact;
  bool JoystickDebug;
};

struct DriveStruct
{
  uint8_t Name_Disk[4][256];
  uint8_t LastNumber_Accessed;
  uint8_t LastAccessType; //Read Write
  bool Error;
  bool isFileAlreadyOpen;
  uint8_t DriveNumber;
};

enum class DiskRomSelection : uint8_t
{
  CP400 = 0,
  CoCo2 = 1
};

extern DiskRomSelection selectedDiskRom;




#define SD_MMC_CMD 38 //Please do not modify it.
#define SD_MMC_CLK 39 //Please do not modify it. 
#define SD_MMC_D0  40 //Please do not modify it.

//-------------Keys definition for Emulator in Custom Menu-----------------------

#define MENU_F12 69
#define MENU_UP 82
#define MENU_DOWN 81
#define MENU_LEFT 80
#define MENU_RIGHT 79
#define MENU_ESC 41
#define MENU_1 30
#define MENU_2 31
#define MENU_3 32
#define MENU_4 33
#define MENU_5 34
#define MENU_6 35
#define MENU_7 36
#define MENU_8 37
#define MENU_9 38
#define MENU_0 39
#define MENU_ENTER 40
#define MENU_PGDWN 78
#define MENU_PGUP 75
#define MENU_DELETE 76
#define MENU_R 21
#define MENU_F 9
#define MENU_D 7
#define MENU_Y 28
#define MENU_N 17
#define MENU_A 4
#define MENU_B 5




//---------------------------------------------------------------

//#define PSRAM_EMU  //Load Rom and RAM of emulation in PSRAM instead of RAM


void DoCPU(void);


#define JOY1_X_AN_PIN 4  //Joy Right X
#define JOY1_Y_AN_PIN 5  //Joy Right Y
#define JOY2_X_AN_PIN 6  //Joy Left X
#define JOY2_Y_AN_PIN 10 //Joy Left Y
#define JOY1_B1 46
#define JOY1_B2 17
#define JOY2_B1 3
#define JOY2_B2 45


//PIA mux order is fixed by the CP400/CoCo hardware: 0=Right X, 1=Right Y, 2=Left X, 3=Left Y
#define JOY1_X_SELECT 0
#define JOY1_Y_SELECT 1
#define JOY2_X_SELECT 2
#define JOY2_Y_SELECT 3

//-----------Videos modes for the emulator
#define VIDEO_MODE_320X240_16_9 0
#define VIDEO_MODE_320X240_4_3 1
#define VIDEO_MODE_640X240_16_9 2
#define VIDEO_MODE_640X240_4_3 3


#define CP400_GRAPH_OFFSET_LEN 512
//For Rom access
#define ROM_OFFSET 0x8000
//#define ROM_OFFSET 0


#define ROM_FF00 0xff00 - ROM_OFFSET
#define ROM_FF01 0xff01 - ROM_OFFSET
#define ROM_FF03 0xff03 - ROM_OFFSET
#define ROM_FF02 0xff02 - ROM_OFFSET
#define ROM_FF03 0xff03 - ROM_OFFSET
#define ROM_FF20 0xff20 - ROM_OFFSET
#define ROM_FF23 0xff23 - ROM_OFFSET
//DISK ACCESS
#define ROM_FF40 0xff40 - ROM_OFFSET
#define ROM_FF48 0xff48 - ROM_OFFSET
#define ROM_FF49 0xff49 - ROM_OFFSET
#define ROM_FF4A 0xff4a - ROM_OFFSET
#define ROM_FF4B 0xff4b - ROM_OFFSET

//For Switch Case
#define M_FF00 0xff00
#define M_FF01 0xff01
#define M_FF02 0xff02
#define M_FF03 0xff03
#define M_FF20 0xff20

#define M_FF22 0xff22

//Disk access
#define M_FF40 0xff40
#define M_FF48 0xff48
#define M_FF49 0xff49
#define M_FF4A 0xff4a
#define M_FF4B 0xff4b

#define M_FFC0 0xffc0
#define M_FFC1 0xffc1
#define M_FFC2 0xffc2
#define M_FFC3 0xffc3
#define M_FFC4 0xffc4
#define M_FFC5 0xffc5
#define M_FFC6 0xffc6
#define M_FFC7 0xffc7
#define M_FFC8 0xffc8
#define M_FFC9 0xffc9
#define M_FFCA 0xffca
#define M_FFCB 0xffcb
#define M_FFCC 0xffcc
#define M_FFCD 0xffcd
#define M_FFCE 0xffce
#define M_FFCF 0xffcf
#define M_FFD0 0xffd0
#define M_FFD1 0xffd1
#define M_FFD2 0xffd2
#define M_FFD3 0xffd3
#define M_FFD4 0xffd4
#define M_FFD5 0xffd5
#define M_FFD8 0xffd8
#define M_FFD9 0xffd9
#define M_FFDE 0xffde //ROM 32K
#define M_FFDF 0xffdf //RAM 32K UPPER
  
  
  
  #define ROM_FF22 0xff22 - ROM_OFFSET  



#define CPU_FAST true // Double Speed (~1.78 MHz)
#define CPU_SLOW false // Single Speed (~0.79 MHz)
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

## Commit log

2026-06-17 First hardware board
    [esp32_coco2.kicad_pcb, esp32_coco2.kicad_sch]
2026-06-17 Add new symbol libraries for ESP32 and power supplies
    - Created a new symbol library for the ESP32 (esp32.kicad_sym) including the esp32-s3-wroom component with detailed pin configurations.
    - Added symbol libraries for PS-12E05 (ps-12e05.kicad_sym) and PS-22F05 (ps-22f05.kicad_sym) with their respective pin definitions.
    - Updated the sym-lib-table to include references to the new libraries for easier access in KiCad.
    [esp32_cp400.kicad_pcb, esp32_cp400.kicad_sch]
2026-06-17 Add font data and testing documentation for ESP32 CP400 emulator
    - Introduced a new font file (CoCO2_3_Fonts.txt) containing character data for the emulator.
    - Created a README file in the test directory to outline the purpose of the directory and provide information on unit testing with PlatformIO.
    - Added a ScrapBook.txt file with various BASIC programs and notes related to disk transactions and graphics modes for reference during development.
2026-06-25 Add footprint for PJ-307 connector
    - Created a new footprint file for the PJ-307 connector in the KiCad format.
    - Included necessary attributes such as reference, value, and layer specifications.
    - Defined pads for through-hole connections with appropriate sizes and drill specifications.
    - Added graphical elements including lines and polygons for silk screen and fabrication layers.
    - Provided a link to the datasheet for reference.
    [esp32_cp400.kicad_pcb, esp32_cp400.kicad_sch]
2026-08-02 Add production files for ESP32 clone hardware
    - Created BOM (bill of materials) file to list components and their specifications.
    - Added designators file to map component designators to their respective quantities.
    - Introduced IPC netlist file for electrical connections and layout.
    - Included positions file to specify component placements on the PCB.
    - Established symbol library table for component symbols used in the design.
    [bom.csv, designators.csv, esp32_clones.kicad_pcb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]
2026-08-17 refactor: rebrand emulator modules for CP400
    - rename emulator source files, headers, symbols, and menu text for CP400
    - move project headers into the src directory
    - standardize file banners and update copyright attribution
    - correct VGA content centering using the active framebuffer dimensions
    - reposition the F12 main menu within the visible VGA area
    - update the VGA sync pin configuration for the ESP32-S3 board
    [CP400Emulator.cpp, CP400Emulator.h]
2026-08-17 feat: add selectable CP400 disk ROM and improve F12 menu
    - embed both CP400 and CoCo 2 disk controller ROMs
    - add a persistent F12 option to select the boot disk ROM
    - default legacy configurations to the CP400 disk ROM
    - centralize menus within a VGA-safe display area
    - clip long filenames to prevent framebuffer overflow
    - reorganize file navigation and disk preview layouts
    - show visible errors for missing or removed microSD cards
    - prevent stale or invalid files from being selected
    - fix out-of-bounds writes when clearing file lists
    [CP400Emulator.cpp, CP400Emulator.h]
2026-08-17 feat: redesign F12 menu and correct video output
    - add PicoVerse-inspired highlighted menu navigation
    - use Up/Down and Enter for menu and submenu selection
    - allow Left/Right to change artifact and Disk ROM options
    - display ESP32 Clone Series title and firmware version
    - center and constrain menus within the VGA-safe area
    - reorganize disk and firmware file-selection screens
    - prevent disk table and footer clipping
    - correct USB HID code for the Right Arrow key
    - fix RGB332 color mapping for BASIC and game graphics
    - add configurable horizontal positioning for game output
    [CP400Emulator.cpp, CP400Emulator.h]
2026-08-18 - Added independent joystick 1 and joystick 2 control mapping from the F12 menu. - Added guided capture for joystick neutral, up, down, left, right, button 1, and button 2 states. - Added persistent 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
2026-08-19 ## 1.11 - 2026-08-19
    ### Added
    - Added a progress gauge that runs while a firmware update is validated and copied.
    ### Changed
    - Moved the USB keyboard port to GPIO11 and GPIO12, joystick 1 to GPIO15 and GPIO16, and joystick 2 to GPIO17 and GPIO18, to simplify cable routing on the board.
    - Gave every F12 screen the same layout, with the product name and screen title in the header, matching separator lines, and key hints in the footer. The disk image picker, firmware update screens, and error messages previously used their own styles.
    - Renamed the "Joystick calibration" menu entry to "Joystick setup".
    - Turned the joystick Serial debug output off by default.
    - Listed only files with a mat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
    [esp32_clones.kicad_pcb, esp32_clones.kicad_sch]
2026-08-26 Refactor code structure for improved readability and maintainability
    [bom.csv, esp32_clones.kicad_pcb, esp32_clones.kicad_sch]
2026-08-29 Add USB-OTG host support for CP400 keyboard
    - Implemented CP400UsbKeyboard.cpp to manage USB keyboard connections using the ESP32-S3 USB-OTG controller.
    - Created CP400UsbKeyboard.h header file to declare functions for starting the USB keyboard and checking connection status.
    - The new implementation allows for full-speed keyboard enumeration and improves compatibility with various USB keyboards.
    - Hardware revision 1.2
    - Moved the keyboard port to the ESP32-S3 native USB-OTG host on GPIO19 and GPIO20, so ordinary full speed USB keyboards now work. The previous bit-banged stack could only talk to low speed devices, 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
    - Re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
    [esp32_clones.kicad_pcb, esp32_clones.kicad_sch]

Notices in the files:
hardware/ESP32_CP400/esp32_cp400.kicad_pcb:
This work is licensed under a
